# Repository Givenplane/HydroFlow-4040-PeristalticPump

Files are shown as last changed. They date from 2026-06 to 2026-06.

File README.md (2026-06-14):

# HydroFlow 4040 Peristaltic Pump 

HydroFlow 4040 Peristaltic Pump

HydroFlow 4040 is an open-source peristaltic pump designed to be simple, affordable and easy to manufacture using common 3D printing equipment and off-the-shelf components.

The project was developed as a practical solution for transferring liquids while keeping the fluid completely isolated from the mechanical components of the pump.

The suitability of the tubing for a specific fluid should be verified by the user according to the tubing manufacturer's specifications.

## Design Specifications

### Tubing

The pump is designed around Tygon F-4040-A tubing 3/16” ID × 5/16” OD (4.8 × 8 mm).
Using different tubing may require modifications to the pump body and rotor geometry.

### Drive Motor

Reference motor used during development:

- Model: JGB37-520-CE

- Voltage: 12 VDC

- Rated Speed: 200 RPM

- Shaft: 6 mm D-shaft

- Gearbox: Metal reduction gearbox

- Rotation: CW / CCW

### Printed Parts

Parts were developed and tested using:

- Printer: Bambu Lab X1 Carbon
- Material: Bambu Lab PETG-HF grey

Standard PETG should also be suitable provided dimensional tolerances are maintained.

### Critical Tolerances

Part accuracy is important for correct operation.

Particular attention should be paid to:

- Rotor-to-shaft fit
- Bearing seats

The rotor must fit the motor shaft without noticeable play.

Excessive clearance may cause vibration, wear and inconsistent pumping performance.

## Print Settings

Reference settings used during development:

- Nozzle: 0.6 mm
- Layer height 0.24 mm
- Perimeters: 4
- Infill: 25 %
- Top layers: 5
- Bottom layers: 5
- X-Y Hole Compensation: 0.10 mm
- X-Y Contour Compensation: 0.075 mm
- Supports: Enabled
- Support Style: Tree (Auto)
- Support Placement: Build Plate Only

Different printers may require calibration adjustments.

## Performance

Reference configuration:

- Tubing: Tygon® F-4040-A

- Tube OD: 5/16” (8.0 mm)

- Tube ID: 3/16” (4.8 mm)

- Motor: JGB37-520-CE

- Supply Voltage: 12 VDC

- Motor Speed: 200 RPM

Measured flow rate:

- Approximately 0.38 L/min

Actual performance may vary depending on tubing condition, fluid viscosity, roller pressure and manufacturing tolerances.

## Resources

[docs/BOM.md](docs/BOM.md)

[doc/WHERE_TO_BUY](docs/WHERE_TO_BUY.md)

- 🎥 YouTube Video: https://youtu.be/laEK1ZIJFD0

- 🎥 YouTube Update Video https://youtu.be/orrYBJg4-Hw
  
- 📐 Onshape CAD: https://cad.onshape.com/documents/38ce336f3ba945738ff4eab6/w/76177a23119b3794901f380b/e/51ffb88a154799f7188256b8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

## Validation and Improvements

Following approximately 30 hours of operation with diesel fuel, two design improvements were implemented:

- The rotor locking system was redesigned using an embedded M4 nut and shaft locking screw.
- Tube retention stops were added to prevent tube migration caused by fuel lubrication.

These improvements are included in the current CAD files,printable parts and BOM.

## License

This project is released under the terms described in LICENSE.txt.

Commercial manufacturing, selling or monetization requires a separate commercial license agreement.

## Author

Simon Given

GivenPlane

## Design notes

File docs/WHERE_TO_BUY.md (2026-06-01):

# Recommended Components

The following links point to components used during development.

## Motor

[Amazon: JGB37-520-CE 12V 200RPM geared motor](https://amzn.to/49A8dol)

## PWM Controller

[Amazon: 5-35V 5A PWM Motor Speed Controller](https://amzn.to/433GbxQ)

## Cooling Fans

[Amazon: 30x30 mm 12V Cooling Fan](https://amzn.to/4ud4FQn)

## Power Supply

[Amazon: 12V 5A power supply](https://amzn.to/434bCYX)

## Tubing
[Amazon: Tygon F-4040-A ](https://amzn.to/4dGL3Pw)

## Affiliate Disclosure

Some links on this page may be affiliate links.

Purchasing through these links helps support the development of open-source projects at no additional cost to you.

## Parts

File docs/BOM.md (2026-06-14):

# Bill of Materials (BOM)

## Fasteners

| Qty | Description | Standard |
|---|---|---|
| 6 | M3 × 10 mm Socket Countersunk Screw | ISO 10642 |
| 7 | M3 × 14 mm Socket Countersunk Screw | ISO 10642 |
| 9 | M3 × 30 mm Socket Cap Head Screw | DIN 912 / ISO 4762 |
| 2 | M3 × 20 mm Socket Cap Head Screw | DIN 912 / ISO 4762 |
| 1 | M4 × 12 mm Socket Cap Head Screw | DIN 912 / ISO 4762 |
| 11 | M3 Hex Nut | DIN 934 |
| 7 | M3 Nylon Lock Nut | DIN 985 |
| 1 | M4 Hex Nut | DIN 934 |

## 3D Printed Parts

| Qty | Description |
|---|---|
| 1 | Cover Cap |
| 1 | Pump Body |
| 1 | Pump Body Cover |
| 1 | Rotor Front |
| 1 | Rotor Rear |
| 2 | 30 × 30 mm Fan Holder |

## Off-the-Shelf Components

| Qty | Description |
|---|---|
| 1 | JGB37-520-CE Geared Motor with Mounting Plate |
| 2 | 30 × 30 mm 12V Cooling Fan |
| 1 | PWM Motor Speed Controller (5–35 VDC, 5 A) |
| 1 | 12 VDC Power Supply (5 A) |
| 1 | Tygon F-4040-A tubing 3/16” ID × 5/16” OD (4.8 × 8 mm) |
| 2 | Brass Hose Barb Union 5 mm × 5 mm (or 3/16" × 3/16") |

## Notes

- The reference motor used during development is an XYT Motor Manufacture JGB37-520-CE (12 V, 200 RPM).
- 30 × 30 mm 12V fans equivalent to common V6 hotend cooling fans can be used.
- Equivalent fasteners from other manufacturers may be used provided dimensions and tolerances are maintained.
- Two straight brass hose barb unions are used as tube retention stops. Commercial 5 mm or 3/16 in hose barb fittings are suitable.

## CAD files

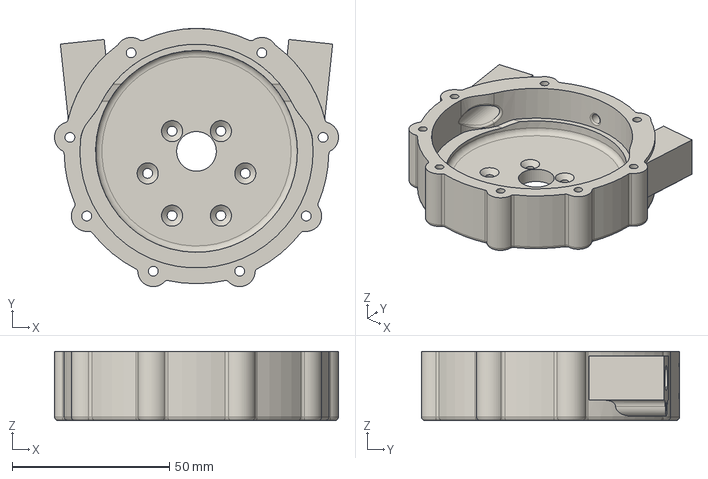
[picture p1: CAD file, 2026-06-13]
3d_models/pump-body.step
90.2 x 82.0 x 22.0 mm

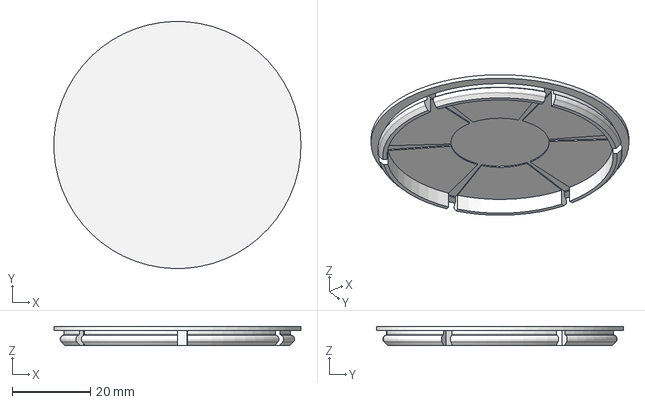
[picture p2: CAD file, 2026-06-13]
3d_models/pump-body-cover.step
63.0 x 63.0 x 4.90 mm

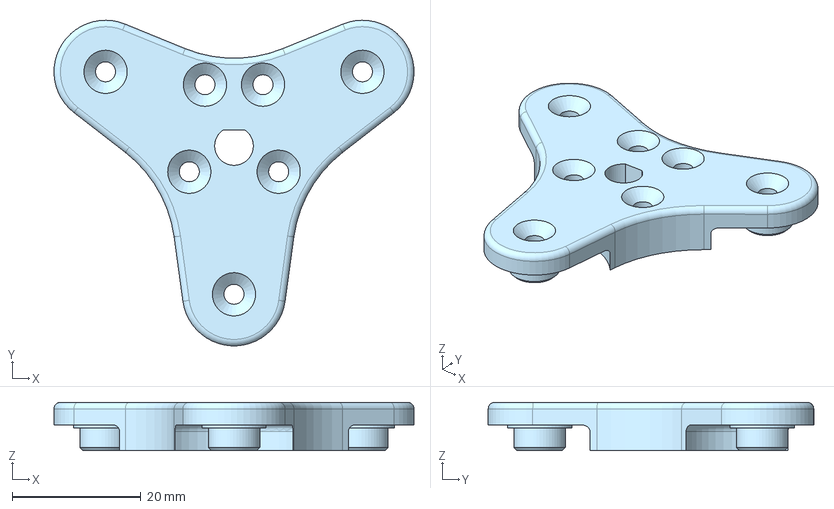
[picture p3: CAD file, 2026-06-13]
3d_models/rotor-front.step
55.8 x 50.5 x 7.50 mm

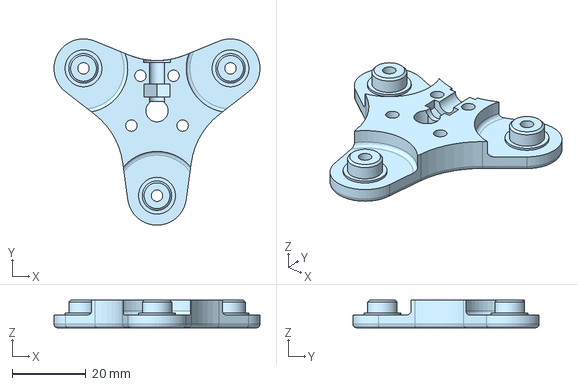
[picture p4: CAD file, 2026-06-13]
3d_models/rotor-rear.step
55.8 x 50.5 x 7.50 mm

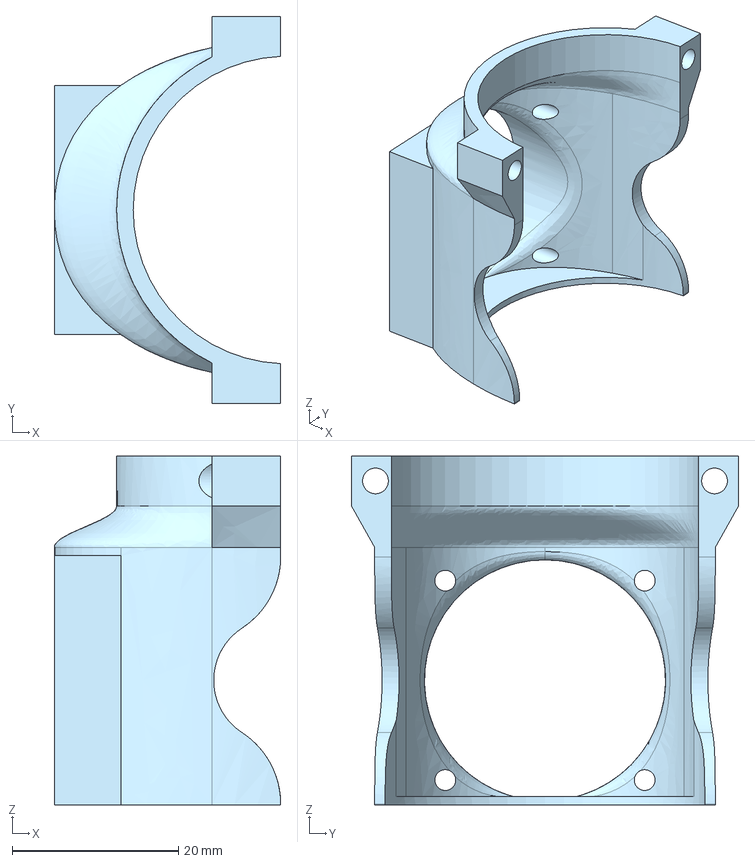
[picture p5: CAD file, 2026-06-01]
3d_models/30x30-mm-fan-holder.step
27.2 x 46.6 x 42.0 mm

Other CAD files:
3d_models/cover-cap.step
3d_models/STL/30x30mm-fan-holder.stl
3d_models/STL/cover-cap.stl
3d_models/STL/rotor-front.stl
3d_models/STL/rotor-rear.stl

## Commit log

2026-06-01 Initial release of HydroFlow 4040 Peristaltic Pump
    [30x30-mm-fan-holder.step, 30x30mm-fan-holder.stl, cover-cap.step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]
2026-06-13 Improve rotor locking system
    [pump-body-cover.step, pump-body.step, rotor-front.step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]
2026-06-14 readme and bom updated
